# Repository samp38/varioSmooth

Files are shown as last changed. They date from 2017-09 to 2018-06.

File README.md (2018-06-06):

# Lightweight solar variometer for free flight

## Purpose
This project is about buiding a simple, lightweight, energey self-sufficient and helmet embbeded variometer. It is small enough to remain in the helmet's inner coat and draws its energy from the sun. A small battery can provide power during shaded times up to 10 hours.

This repo containsthe sources, pcb design files (eagle format), gerber files and a few instructions to build it, including pictures and bill of materials. The firmware must be loaded into the pic, so you will need a programmer such as a PICKIT or some arduino DIY one.

Key features :
- 1mA@3V power consumption
- 0.1 m/s detection threshold
- no need to recharge or change battery
- embedded in helmet
- 22mm x 17mm pcb size

## Electronic parts needed
The variometer transcribes vertical speed to audio signal and must contain a power manager with a solar panel and a backup battery. Here are the comonent nedded :

* **[MS5611](http://www.te.com/usa-en/product-CAT-BLPS0036.html)** : absolute pressure sensor.

* **[PIC24F16KA101](https://www.microchip.com/wwwproducts/en/PIC24F16KA101)** : this microcontroller is the brain of the vario. It communicates with the pressure sensor, does all the calculations and generates the audio signal. You mest get the 20 leads SSOP package.

* **[MCP4542](https://www.microchip.com/wwwproducts/en/MCP4542)** : Microchip digital I2C potentiometer used to adjust audio volume.

* **[ADP160](http://www.analog.com/en/products/power-management/ldo-linear-regulators/positive-linear-regulators/adp160.html)** : Analog Device ultra low quiescent current ldo regulator. It supplies stabilized power to electronics. Get the 2.8 or 3V version.

* **[LTC4071](http://www.analog.com/media/en/technical-documentation/data-sheets/4071fc.pdf)** : power manager. It havests solar energey and manages system load supplying/battery charging/power path handling. The current shunt limit is 50mA, so make sure your solar panel maximum current is under this value.

* **solar cell** : power supply. The system is designed for 6V/50mA max solar panel. I use two flexible 3V/12mA solar cells (ref [sp3-12](http://www.flexsolarcells.com/index_files/OEM_Components/Flex_Cells/pages/PowerFilm-Solar-OEM-00-Solar-Cell-Module-SP3-12.php)).

* **buzzer** : i like the kingstate's [KPEG006](http://uk.farnell.com/kingstate/kpeg006/receiver-piezo-leads/dp/1299873). It is flat and easy to fit under inner coat.

* **schottky diode** : used to protect solar panel. I use a [Nexperia 1PS76SB10](http://fr.farnell.com/nexperia/1ps76sb10/diode-schottky/dp/1081179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).

* **3.6 lithium ion battery**. I use a [LIR2016](http://www.eemb.com/public/image/download/LIR2016.pdf).

* some capacitors and resistors (0603 package)

For detailed list of components, including packages and values, see the [part list](https://github.com/samp38/varioSmooth/blob/master/doc/partList.txt).

## PCB
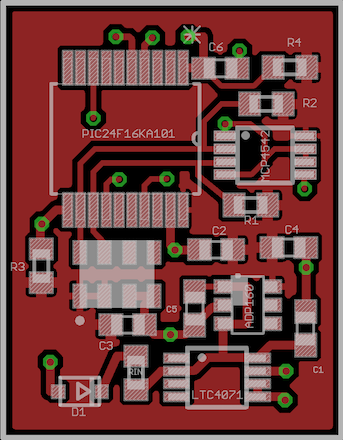
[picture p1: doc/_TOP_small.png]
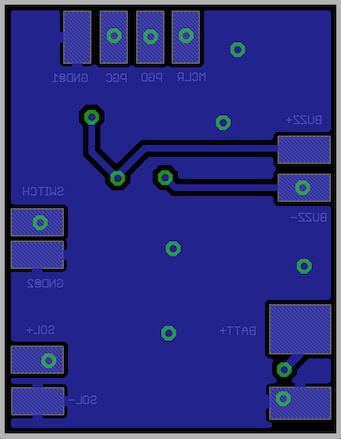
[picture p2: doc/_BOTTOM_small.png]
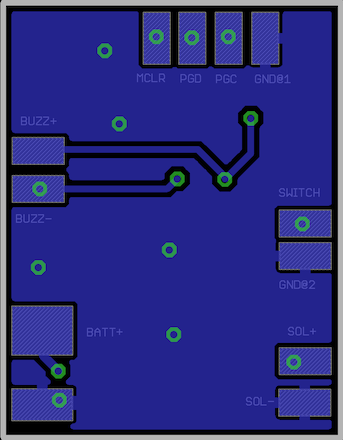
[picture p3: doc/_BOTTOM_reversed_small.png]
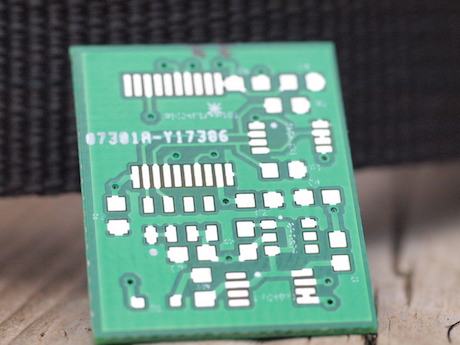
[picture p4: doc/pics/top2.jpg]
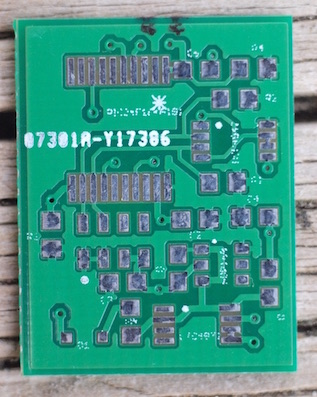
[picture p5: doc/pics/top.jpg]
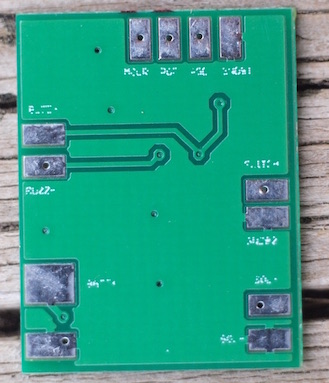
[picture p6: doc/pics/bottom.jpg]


The schematics and GERBER files are in the [pcb folder](pcb).  [iTead pcb protoyping service](https://www.itead.cc/open-pcb/pcb-prototyping/2layer-green-pcb-5cm-x-5cm-max.html) is a good deal to get your boards (10$ for 10 pieces).

## Programming the board
### Binary  file
The code can be found in the [MPLABX project folder](VarioSMooth.X). Microchip's MPLABX IDE is free, as is the XC16 compiler. If you don't feel like building it, just download the [binary file](https://github.com/samp38/varioSmooth/releases/download/v/VarioSMooth.hex) in the [releases page](https://github.com/samp38/varioSmooth/releases).

### Upload to the board
The PIC can be programmed via the MCLR, PGC and PGD pads on the bottom of the board. Ground and a Power must also be ok (VCC from programmer or the solar panel/battery). I used a PICKT 2, very cheap programmer for PICs.
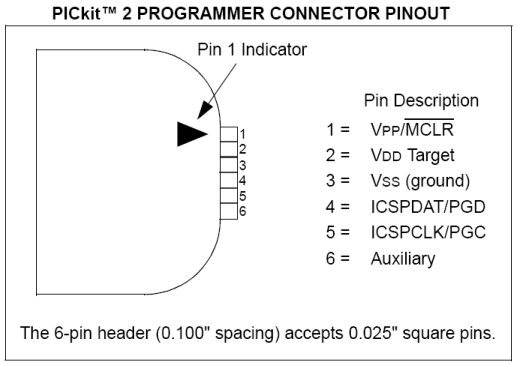
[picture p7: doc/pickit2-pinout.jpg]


## Wiring & Using
The following elements are to be connected to the board (bottom pads) :
* Switch ('momentary on', i use a key switch like [this one](https://goo.gl/images/q1apYJ)). Pads **SWITCH** and **GND**.
* Solar panel. Pads **SOL+** and **SOL-**.
* Buzzer. Pads **BUZZ+** and **BUZZ-**.
* Battery. Pads **BATT+** and **GND**.

Once everything is set up, just get your solar panel under the sun and it should start up. Short press on button allows to start up or adjust volume, long press to shut down. A 2 minutes time out is set up in order to shut down the system if there is no move detected.

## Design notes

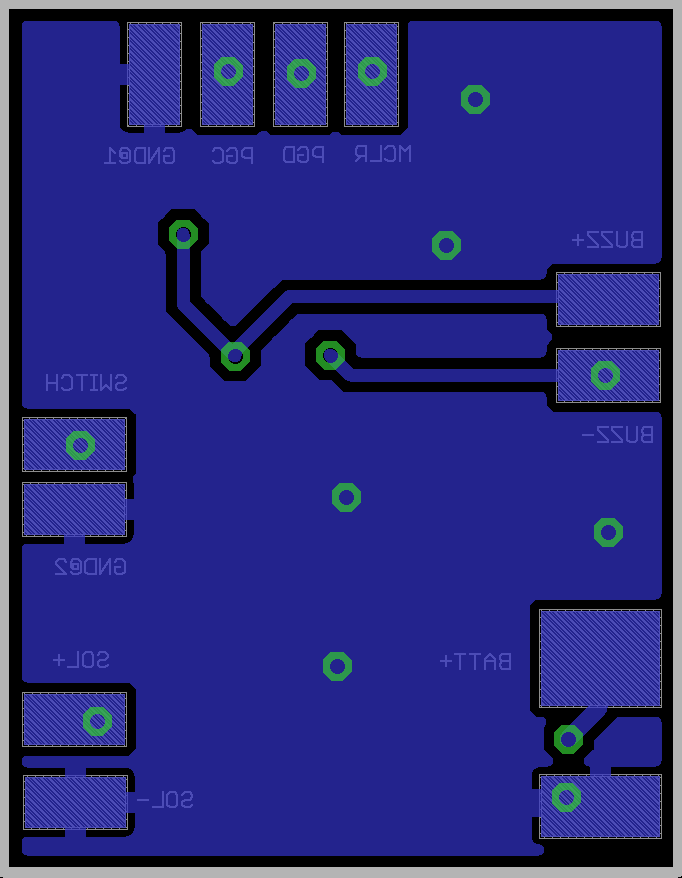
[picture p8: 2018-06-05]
doc/_BOTTOM.png

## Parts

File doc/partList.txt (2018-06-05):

Partlist

Exported from Vario 0.1 Ultra Mini.brd at 05/06/2018 13:43

EAGLE Version 7.3.0 Copyright (c) 1988-2015 CadSoft

Assembly variant: 

Part          Value                Package       Library                 

R1            10k                  R0603         rcl                     
R2            10k                  R0603         rcl                     
R3            10k                  R0603         rcl                     
R4            10k                  R0603         rcl                     
RIN           440                  R0603         rcl                     
C1            1µ                   C0603         rcl                     
C2            100nF                C0603         rcl                     
C3            100nF                C0603         rcl                     
C4            1µ                   C0603         rcl                     
C5            1µ                   C0603         rcl                     
C6            100nF                C0603         rcl                     
D1            1PS76SB10            SOD323-R      Nexperia                
ADP160        2.8 or 3V            TSOT23-6_DDC  analog-devices          
LTC4071       LTC4071              MSOP8         linear-technology       
MCP4542       MCP4542              MSOP8         microchip               
MS5611        MS5607               MS5607-02BA03 measurement_specialties 
PIC24F16KA101                      SSOP20_MC     microchip               
BUZZER        KPEG006                            kingstate

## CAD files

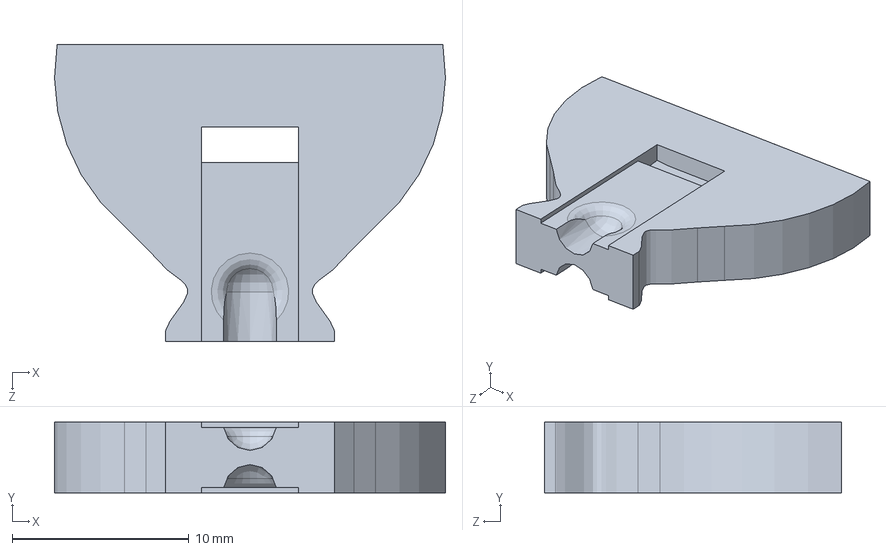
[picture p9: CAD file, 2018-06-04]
cad/lir_holder/LIR2016_Holder.SLDPRT
22.1 x 4.00 x 16.8 mm

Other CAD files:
cad/lir_holder/LIR2016_Holder.STL

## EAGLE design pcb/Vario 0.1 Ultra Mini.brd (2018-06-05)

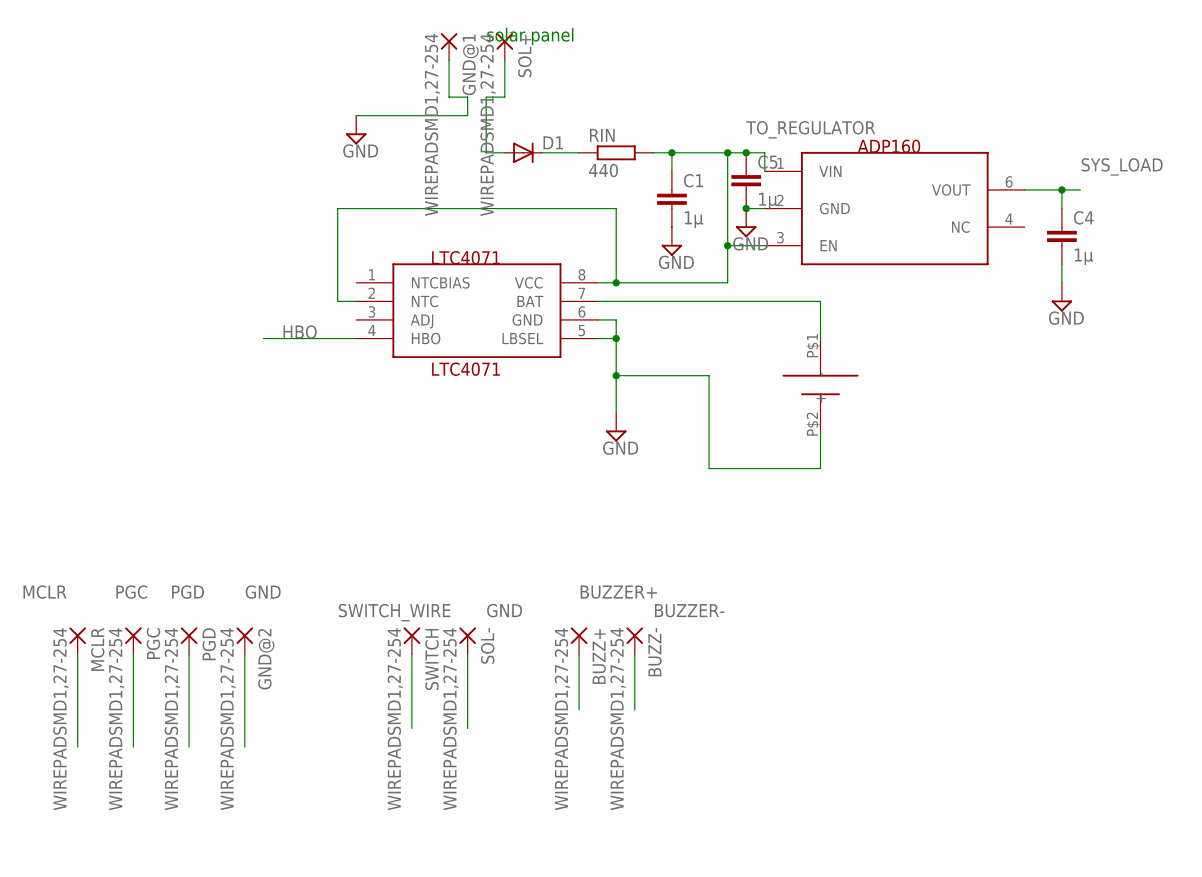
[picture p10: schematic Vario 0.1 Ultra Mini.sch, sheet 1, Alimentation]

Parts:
ADP160: ADP160/161/162/163; TSOT23-6_DDC
BATT+: VARIO_LIPO
BUZZ+: WIREPADSMD1,27-254; SMD1,27-2,54
BUZZ-: WIREPADSMD1,27-254; SMD1,27-2,54
C1, C4, C5: 1µ; C0603
D1: DIODE-SOD323-R; SOD323-R
GND@1, GND@2: WIREPADSMD1,27-254; SMD1,27-2,54
LTC4071: LTC4071; MSOP8
MCLR: WIREPADSMD1,27-254; SMD1,27-2,54
PGC: WIREPADSMD1,27-254; SMD1,27-2,54
PGD: WIREPADSMD1,27-254; SMD1,27-2,54
RIN: 440; R0603
SOL+: WIREPADSMD1,27-254; SMD1,27-2,54
SOL-: WIREPADSMD1,27-254; SMD1,27-2,54
SWITCH: WIREPADSMD1,27-254; SMD1,27-2,54

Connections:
BATT: BATT+.P$1 (+), LTC4071.7 (BAT)
BUZZER+: BUZZ+.1; also elsewhere on the board
BUZZER-: BUZZ-.1; also elsewhere on the board
GND: ADP160.2 (GND), BATT+.P$2 (-), C1.2, C4.2, C5.2, GND@1.1, GND@2.1, LTC4071.5 (LBSEL), LTC4071.6 (GND), SOL-.1; also elsewhere on the board
HBO: LTC4071.4 (HBO)
MCLR: MCLR.1; also elsewhere on the board
unnamed: D1.C, RIN.1
PGC: PGC.1; also elsewhere on the board
PGD: PGD.1; also elsewhere on the board
SOL+: D1.A, SOL+.1
SWITCH_WIRE: SWITCH.1; also elsewhere on the board
SYS_LOAD: ADP160.6 (VOUT), C4.1; also elsewhere on the board
TO_REGULATOR: ADP160.1 (VIN), ADP160.3 (EN), C1.1, C5.1, LTC4071.2 (NTC), LTC4071.8 (VCC), RIN.2

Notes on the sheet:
solar panel

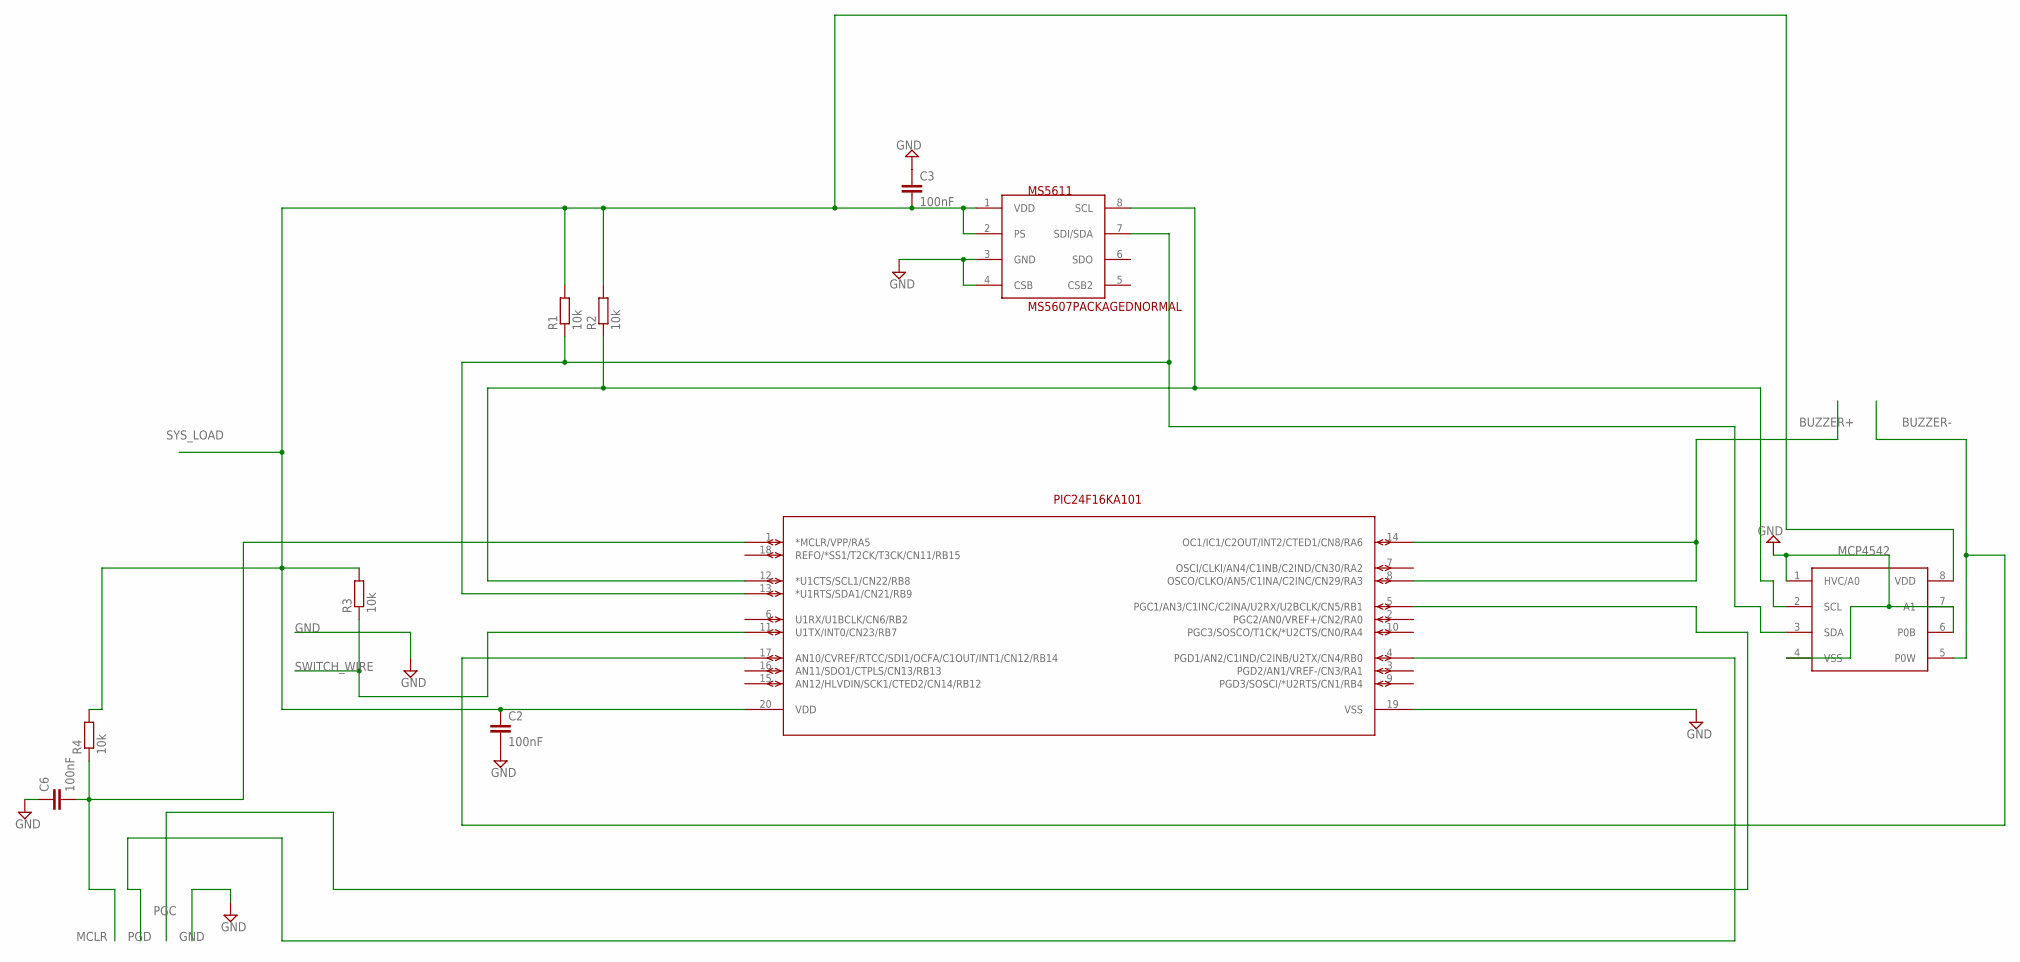
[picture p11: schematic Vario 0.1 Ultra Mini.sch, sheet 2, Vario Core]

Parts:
C2, C3, C6: 100nF; C0603
MCP4542: MCP4542; MSOP8
MS5611: MS5607PACKAGEDNORMAL; MS5607-02BA03
PIC24F16KA101: PIC24F16KA101-X_; SSOP20_MC
R1, R2, R3, R4: 10k; R0603

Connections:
BUZZER+: PIC24F16KA101.8 (OSCO/CLKO/AN5/C1INA/C2INC/CN29/RA3), PIC24F16KA101.14 (OC1/IC1/C2OUT/INT2/CTED1/CN8/RA6); also elsewhere on the board
BUZZER-: MCP4542.5 (P0W), PIC24F16KA101.17 (AN10/CVREF/RTCC/SDI1/OCFA/C1OUT/INT1/CN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); also elsewhere on the board
GND: C2.2, C3.1, C6.1, MCP4542.1 (HVC/A0), MCP4542.4 (VSS), MCP4542.6 (P0B), MCP4542.7 (A1), MS5611.3 (GND), MS5611.4 (CSB), PIC24F16KA101.19 (VSS); also elsewhere on the board
MCLR: C6.2, PIC24F16KA101.1 (*MCLR/VPP/RA5), R4.1; also elsewhere on the board
PGC: PIC24F16KA101.5 (PGC1/AN3/C1INC/C2INA/U2RX/U2BCLK/CN5/RB1); also elsewhere on the board
PGD: PIC24F16KA101.4 (PGD1/AN2/C1IND/C2INB/U2TX/CN4/RB0); also elsewhere on the board
SCL: MCP4542.2 (SCL), MS5611.8 (SCL), PIC24F16KA101.12 (*U1CTS/SCL1/CN22/RB8), R2.1
SDA: MCP4542.3 (SDA), MS5611.7 (SDI/SDA), PIC24F16KA101.13 (*U1RTS/SDA1/CN21/RB9), R1.1
SWITCH_WIRE: PIC24F16KA101.11 (U1TX/INT0/CN23/RB7), R3.1; also elsewhere on the board
SYS_LOAD: C2.1, C3.2, MCP4542.8 (VDD), MS5611.1 (VDD), MS5611.2 (PS), PIC24F16KA101.20 (VDD), R1.2, R2.2, R3.2, R4.2; also elsewhere on the board

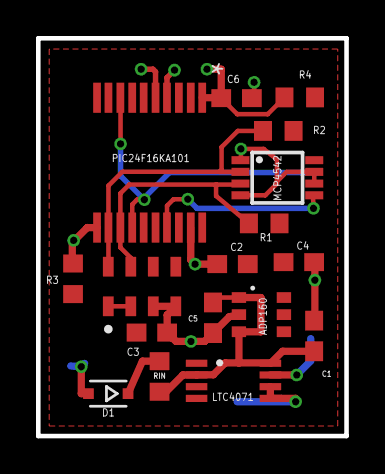
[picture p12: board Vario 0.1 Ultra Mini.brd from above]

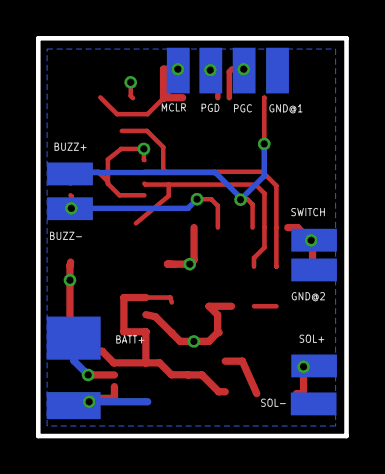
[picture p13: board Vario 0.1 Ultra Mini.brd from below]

Board: 2 copper layers, 17.1 x 22.1 mm, 28 parts (11 on the bottom side), 14 nets.

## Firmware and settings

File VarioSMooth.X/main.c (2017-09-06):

#include "pic24_all.h"

#include "i2c.h"
#include "timers.h"
#include "sensor.h"
#include "audio.h"
#include "filters.h"
#include "vario.h"
#include "button.h"

//#define DEBUG
#define ELLE_AIME_LA_BITE

#ifdef DEBUG
    #include <stdio.h>
    #include "uart.h"
    char dbgBuf[50];
#endif

#define NBVALUES 10
s32 values[NBVALUES];
u8 values_i = 0;

_FBS( BSS_OFF & BWRP_OFF )
_FGS( GSS0_OFF & GWRP_OFF )
_FOSCSEL( FNOSC_LPFRCDIV & IESO_OFF )
_FOSC( FCKSM_CSECMD & POSCFREQ_100KHZ & OSCIOFNC_ON & POSCMOD_NONE)
_FWDT( FWDTEN_OFF & WINDIS_OFF & FWPSA_PR128 & WDTPS_PS32768 )
_FPOR( MCLRE_ON & BORV_1_8V & AI2C1SEL_PRI & PWRTEN_OFF & BOREN_BOR3)
_FICD( BKBUG_OFF & COE_OFF & ICS_PGx3 )
_FDS( DSWDTEN_OFF & DSBOR_OFF & RTCCREF_OFF & DSWDTLPRC_OFF & DSWDTPS_DSWDTPS_0 )


volatile u8 tmr1_waiting = 0;
u8 sns_status = 0;

// Raw value of the pressure (coming straight out of the ADC)
u32 Praw = 0;
// compensated pressure value
s32 PressureComp = 0;

#define INTRO_LENGTH 7
u32 intro_freqs[INTRO_LENGTH] = {440, 0,  698, 0,  659, 0,  587};
u32 intro_times[INTRO_LENGTH] = {600, 40, 600, 40, 600, 40, 1200};

// Linear Regression
//void nextFitSpeed(s64 *speed) {
//    u16 i  = 0; // t index
//    u16 i_ = 0; // corresponding index in sample in array
//    u32 X_SUM = 465L;
//    u32 DENOM = 337L;
//    u64 XY_SUM = 0LL;
//    u64 Y_SUM = 0LL;
//    for(i=0;i<MEASURE_BUFFER_SIZE;i++) {
//        i_ = i+pressure_count;
//        if (i_ >= MEASURE_BUFFER_SIZE) {i_ = i+pressure_count - MEASURE_BUFFER_SIZE;}
//        Y_SUM = Y_SUM + filteredSamplesBuffer[i_];
//        XY_SUM = XY_SUM + ((i+1) * filteredSamplesBuffer[i_]);
//    }
//    *speed = 10 + (((s64)X_SUM * (s64)Y_SUM) - (MEASURE_BUFFER_SIZE * (s64)XY_SUM) ) / ((s64)DENOM);
//}

void startElapsedTime(void) {
    tmr1_Start(100000);
    _T1IE = 0;
}

#ifdef DEBUG
void printElapsedTime(void) {
    sprintf(dbgBuf, "Elapsed Time = %u ms\r\n", TMR1);
    tmr1_Stop();
    uart_Print(dbgBuf);
    sns_status = 0;
    sns_TriggerTemperatureSample();
    tmr1_Start(MEASURE_PERIOD_T);
}
#endif

void mcu_Init(void) {
    AD1PCFG = 0xFFFF;            // set all analog-input enabled pins (ANx) to digital mode
    CLKDIVbits.RCDIV = 0;  	 // LPFRC oscillator 500kHz divided by 1
    CONFIG_RB2_AS_DIG_INPUT();  // 6 : gpioDbg
    CONFIG_RA4_AS_DIG_INPUT();   // DEBUG
    CONFIG_RA6_AS_DIG_OUTPUT();  // 14 : Audio output
//    CONFIG_RB14_AS_DIG_OUTPUT();  // 14 : Comparator output
    CONFIG_RB14_AS_DIG_INPUT();

    _DSSR = 0;      // clear RELEASE bit
    _INT0IE = 0;    // only enabled when entering deep sleep mode
    _INT0 = 0;      // Clear Deep Sleep on INT0 edge flag

    #ifdef DEBUG
        uart_Config();
    #endif

    i2c_Config();
    tmr1_Config();
    tmr2_Config();
    tmr3_Config();

    button_Config();
    audio_Config();
}


void tmr1_callback(void) {
    tmr1_Stop();    
    if (tmr1_waiting) {
        tmr1_waiting = 0;
    } else {
        ClrWdt();
        _IDLE = 0;
        if (sns_status) {            
            ///////////////////////////////////           
            sns_ReadADC(&Praw);
            sns_TriggerTemperatureSample();            
            /////////////////////////////////// 2ms
            tmr1_Start(MEASURE_PERIOD_T);
        } else {
            u32 Traw;
            sns_ReadADC(&Traw);
            sns_TriggerPressureSample();
            tmr1_Start(MEASURE_PERIOD_P);
            sns_CompensateTemperature(Traw);
            PressureComp = sns_CompensatePressure(Praw);
            vario_ping(PressureComp);
            //sprintf(dbgBuf,"%lu \r\n",PressureComp);
            //uart_Print(dbgBuf);
        }
        sns_status = !sns_status;        
        Idle();         // Save Power
    }
}


void wait(u32 ms) {
    tmr1_Stop();
    tmr1_waiting = 1;
    tmr1_Start(10 * ms);

    while (tmr1_waiting){
        Nop();
    }
}

int main(void) {    
    mcu_Init();
    ClrWdt();  
    sns_Reset();
    wait(2000);
    audio_Beep(0);
    sns_Config();
    sns_status = 0;
    setPreviousVolume();
#ifdef ELLE_AIME_LA_BITE
    u8 intro_i;
    for (intro_i = 0; intro_i < INTRO_LENGTH; intro_i++) {
        audio_Beep(intro_freqs[intro_i]);
        wait(intro_times[intro_i]);
    }
    audio_Beep(0);
#else
    audio_Beep(220);
    wait(80);
    audio_Beep(1100);
    wait(80);
    audio_Beep(2200);
    wait(80);
    audio_Beep(0);
#endif
    sns_TriggerTemperatureSample();
    tmr1_Start(MEASURE_PERIOD_T);
    vario_init();
    button_Config();
    while(1){        
        Nop();
    }
    return 0;
}

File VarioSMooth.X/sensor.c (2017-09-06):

#include "pic24_all.h"
#include "i2c.h"

#define I2C_ID_MS5611    ((u8)0b11101110)
#define I2C_ID_MS5611_RST ((u8) 0x1E)
u8 I2C_ID_MS5607_C[7] = {0, 0b10100010, 0b10100100, 0b10100110, 0b10101000, 0b10101010, 0b10101100 };
#define I2C_ID_MS5611_CONVERT_PRESSURE_4096 ((u8)0x48)
#define I2C_ID_MS5611_CONVERT_TEMP_4096     ((u8)0x52)
#define I2C_ID_MS5611_READ_ADC              ((u8)0x00)


// MS5611 calibration coefficients
u16 COEFS[7];

s32 dT = 68;
// D2 typical value : 8077736
void sns_CompensateTemperature(u32 D2)	{
    // Difference between actual and reference temperature
    dT = D2 - ((u32)COEFS[5] << 8); // dT easily goes up to 250000     C5*256 = 8 256 000
    // Actual temperature (-40 unsigned long 85°C with 0.01°C resolution)
//    s32 TEMP = 2000 + ((dT * (s64)COEFS[6]) >> 23);
}

s32 sns_CompensatePressure(u32 D1)  {
//    sprintf(dbg, "%lu\t", D1);
//    uart_Print(dbg);
//    sprintf(dbg, "%ld\t", dT);
//    uart_Print(dbg);
    // Offset at actual temperature
    s64 OFF = ((s64)COEFS[2] << 16) + (((s64)COEFS[4] * dT) >> 7);
//    sprintf(dbg, "%lld\t", OFF);
//    uart_Print(dbg);
    
    // Sensitivity at actual temperature
    s64 SENS = ((s64)COEFS[1] << 15) + (((s64)COEFS[3] * dT) >> 8);
//    sprintf(dbg, "%lld\t", SENS);
//    uart_Print(dbg);
    // Temperature compensated pressure (10 to 1200mbar with 0.01mbar resolution)
    s32 P = (((D1 * SENS) >> 21 ) - OFF) >> 15;
    
    return P;
}

// Trigger a Pressure measurement and conversion
void sns_TriggerPressureSample(void) {
    i2c_Write1(I2C_ID_MS5611,I2C_ID_MS5611_CONVERT_PRESSURE_4096);
}

// Trigger a Temperature measurement and conversion
void sns_TriggerTemperatureSample(void) {
    i2c_Write1(I2C_ID_MS5611,I2C_ID_MS5611_CONVERT_TEMP_4096);
}

// Read the result of the conversion (temperature or pressure)
void sns_ReadADC(u32 * value) {
    u8 temp[3];
    i2c_RcvBuf(I2C_ID_MS5611,I2C_ID_MS5611_READ_ADC,3,temp);

    Nop();
    Nop();
    Nop();
    
    *value = 0X00000000 | temp[0];
    *value = *value << 8 | temp[1];
    *value = *value << 8| temp[2];
}

// Reset the sensor : load the calibration coefficients into the memory
void sns_Reset(void) {
    i2c_Write1(I2C_ID_MS5611, I2C_ID_MS5611_RST);
}

/**
 * call sns_Reset, wait, then call this
 * Read the calibration coefficient for the calculations
 */
void sns_Config(void) {
    u8 b[2];

    int i = 1;
    for (; i <= 6; i++) {
        i2c_RcvBuf(I2C_ID_MS5611, I2C_ID_MS5607_C[i], 2, b);
        COEFS[i] = ((u16) b[0] << 8) | (u16)b[1];
    }
}

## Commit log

2018-06-04 Doc
    Doc
    [LIR2016_Holder.SLDPRT, LIR2016_Holder.STL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]
2026-10-16 Fix build with XC16 2.10 FIX THE LEGENDARY LANDING BUG
    - include <xc.h> instead of the case-mismatched device header
    (broke on case-sensitive filesystems)
    - drop non-static inline on functions called from other files
    (C99 inline semantics: no external definition emitted)
2026-10-17 Port PCB from Eagle to KiCad 10
    - Move Eagle sources and Gerbers to pcb/eagle/ (archive)
    - Import project into pcb/kicad/varioSmooth_v1/ with project-local
    symbol and footprint libraries
    - Clean up schematic: remove dangling wires, add no-connect markers
    and PWR_FLAGs
    - Fix pin electrical types inherited from Eagle (LTC4071 LBSEL,
    ADP160 VOUT, MCP4542, battery pads)
    - ERC clean; netlist identical to the Eagle design
    - Ignore KiCad local files (.kicad_prl, .history, backups, locks)
2026-10-17 Fix false climb spike around 983 mbar (landing bug)
    filterPressure() and speedIIRFilter() were called from vario.c without
    a prototype. XC16 then assumed a 16-bit int return value, truncating
    the filtered pressure (s32, 0.01 mbar) to its low 16 bits. Crossing
    983.04 mbar (0x18000) made the stored value jump by 65536, read as a
    huge vertical speed: the vario went crazy briefly when landing in
    the plains.
    - Include filters.h in vario.c and timers.h in audio.c
    - Fix tmr2_Start() and sns_ReadADC() prototypes
    - Document the fix in README open issues
2026-10-17 Freeze v2 power block on LTC4071, document v1 charger findings
    - v2: keep LTC4071 with SP3-12 cells in series (side by side on the
    helmet top), RIN 0 ohm, NTC on battery, LBSEL to VCC; MDBT50Q
    supplied from VCC through VDDH, REGOUT0 3.0 V, 32.768 kHz crystal
    - BQ25505/AEM10941 MPPT option evaluated and dropped
    - README: v1 LTC4071 config verified, RIN is 220 ohm on the board,
    possible battery reconnection issue with LBSEL to GND.
2026-10-18 Split repo into v1/ and v2/, add v2 firmware skeleton
    - Move the PIC24 v1 (firmware, pcb, cad, doc, README) under v1/ and the
    v2 design notes to v2/README.md
    - Stop tracking v1 build outputs (build/, dist/), now ignored
    - v2 firmware (PlatformIO, Feather nRF52840): MS5611 driver with PROM
    CRC and 2nd order compensation, v1 sampling scheme (pressure OSR 4096
    + temperature every sample) and vario algorithm in floating point,
    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
2026-10-18 Add v1 beeps on the piezo, 4 s sensor warm-up
    - audio.*: v1 beep tables (beepLen / audioFreq, tone at 2/3), silent when
    sinking. The piezo sits between A0 and A1, driven in opposite phase by
    one PWM peripheral, like the v1 "boost" volume where the comparator
    produced the inverted signal. Full volume only for now.
    - Wait 4 s (200 samples, as in v1) before starting the vario: sampling at
    50 Hz warms the sensor up by ~0.6 °C and ~25 Pa in the first second,
    which showed as a false sink. Filters restarted, nothing sent or played
    during warm-up.
    - Print the measured sample rate and late/skipped counters.
    - README: audio module and piezo wiring.
2026-10-19 Add volume levels and power off on the user button, as in v1
    - Short press: next volume (medium, high, boost) with the v1 volume
    change melody. Long press (> 0.5 s): shutdown melody, then System OFF
    once the button is released; the button wakes the board up (reset).
    - Volumes: boost = A0/A1 in opposite phase, high = A0 only, medium = A2
    through a ~1 kOhm resistor (v1: digital pot), A0 high impedance. A
    shorter duty cycle did not work: every edge rings the piezo the same.
    - Save the volume in flash at power off only: a flash write blocks
    ~0.5 s, the sensor cools down during the pause and the vario sees a
    false climb.
    - Start-up melody; melodies are non-blocking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
2026-10-19 Play the start-up melody right after reset
    Don't wait up to 2 s for the USB serial before starting: it is
    re-enumerated at every wake-up from System OFF, so the wait nearly always
    ran to its timeout. The start-up info is printed at the end of the
    warm-up instead, with the time since reset.
2026-10-19 Disable the Bluefruit connection LED
    The final board has no LED, and on the Feather the blue LED keeps its
    state in System OFF: powered off while connected or mid-blink, it stayed
    lit and drew ~1 mA. The ble= field of the debug output shows the
    connection instead.
2026-10-19 Add the v2 KiCad project with the MDBT50Q and an LTC4071 symbol
    Project library varioSmooth_v2 with the LTC4071 (MS8E) symbol on the
    stock MSOP-8 exposed pad footprint; pad 9 stacked on GND. U1 MDBT50Q-1MV2
    placed in the schematic.
2026-10-20 Draw the v2 schematic: power, USB, sensor, audio and debug
    LTC4071 shunt charger fed by the solar cells and by USB VBUS through
    Schottky diodes; MDBT50Q in high voltage mode (VDDH from the battery,
    REG0 DC/DC to a 3.3 V VDD). USB-C with CC pull-downs and USBLC6 ESD
    protection, MS5611 on I2C, piezo, button and 32 kHz crystal on the
    Feather pins so the firmware is unchanged, SWD and reset test pads.
2026-10-20 Split the project into a cockpit extension and a helmet vario
    The in-helmet vario piles up conflicting constraints (BLE antenna, small
    battery, wires through the vents). Plan two devices instead: a phone
    extension for the cockpit with GNSS and IGC backup logging, built on the
    current schematic, then a minimal vario in a small box on a helmet strap.
    The schematic so far: LTC4071 charger, MDBT50Q in high voltage mode,
    USB-C with ESD protection, MS5611, piezo, button, 32 kHz crystal and
    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
2026-10-22 Place and route the v2 helmet vario PCB
    Two-layer 20 x 32.75 mm board, single-sided assembly. The MDBT50Q antenna
    sits flush with the top edge and the USB-C receptacle at the bottom.
    Wire pads (solar cells, battery, buzzer, button) and the SWD/RESET/3V3/GND
    test pads are on the back.
    Routing was done by hand: the 32 kHz crystal next to the module, the
    VDDH/DCCH/L1 loop under it, USB D+/D- through the USBLC6 flow-through
    pads, then power, I2C, buzzer and SWD. GND pours cover both layers with
    stitching vias. The remaining DRC errors come from the USB-C footprint
    itself (hole clearance, starved thermals on A1/B12).
    Board rules: 0.15 mm minimum track, 0.3 mm edge clearance,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
2026-10-22 Redefine the helmet vario and the cockpit extension
    The helmet vario keeps the nRF52840 to send baro and vario to XCTrack,
    is integrated in the helmet and drops USB: SWD flash once, then BLE OTA,
    with the P1.02 button as DFU recovery. The routed board becomes the
    development prototype before a compact USB-less version. Keep the
    MDBT50Q vs ISP1807 module choice open for the compact board.
    The extension becomes a phone power bank (18650 1S, BQ25895-class
    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
2026-10-23 Make the debug output selectable, with RTT over SWD
    The helmet board has no USB, so the debug log can no longer go to the
    USB serial port. DEBUG_OUTPUT now picks the output at build time:
    0 = none, 1 = USB serial, 2 = SEGGER RTT, read over the SWD pads with
    a CMSIS-DAP probe (probe-rs attach). RTT stays in the core's default
    non-blocking mode, so the firmware runs on when no probe reads the
    buffer. The new rtt environment builds with RTT.
